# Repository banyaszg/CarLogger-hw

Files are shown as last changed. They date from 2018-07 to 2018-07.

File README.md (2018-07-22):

# CarLogger-hw
OBD-II CAN logger based on Particle Electron(Photon). With Particle Electron it can monitor 2 CAN buses. So it can handle the Medium Speed CAN bus of Mazda and Ford cars.

# Motivation
My main project is designing a remote surveillance system for my car, which connects to the OBD-II CAN buses and sends notification to my phone. I'm mainly interested in security related information (lock, doors, alarm), and battery power. So the standard OBD communication protocol doesn't cover these signals. I have to find them in the proprietary communication. I designed this device to check whether I can reverse engineer the needed part of the Mazda communication protocol.
This device can also be used as the first version of the surveillance system. It has 3 extension connectors for GPS an other sensors.

# Features
* 2 High-speed CAN transceivers
* Power from the OBD-II port using a DC/DC buck converter
* Use with Particle Photon (1 CAN) or Particle Electron (2 CAN)
* MicroSD card
* Battery monitoring
* With Particle Electron and battery it can turn off the DC/DC converter to save the car's battery
* The CAN transceivers can work from the battery of the Particle Electron
* 3 [Grove](http://wiki.seeedstudio.com/Grove_System/) compatible connectors

# Hardware
* [Schematic (PDF)](CarLogger.PDF)
* [Gerber](Gerber)
* [Drill](NC-Drill)
* [Bill of materials](BOM/Bill%20of%20Materials-CarLogger.xls) (Use Grove connectors instead of JST!)
* The PCB fits into this [case](https://www.aliexpress.com/item/16Pin-OBD2-Connector-J1962m-Handle-Connector-DIY/32782473183.html)

A Particle [Photon](https://docs.particle.io/datasheets/photon-(wifi)/photon-datasheet/) or [Electron](https://docs.particle.io/datasheets/electron-(cellular)/electron-datasheet/) is required.

# Software
* The [CarLogger firmware](https://github.com/banyaszg/CarLogger-sw) is used for logging.

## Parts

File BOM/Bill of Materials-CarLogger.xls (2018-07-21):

Comment | Datasheet URL | Description | Designator | Footprint | LibRef | Manufacturer | Manufacturer Part Number | Quantity
100nF |  | Capacitor | C3, C4, C8, C11 | FP_0805_CAP_085 | CAP | TDK | CGA4J3X7T2E104K125AA | 4
100uF |  | Polarized Capacitor | C7 | FP_7343 | CAP_ELECT | KEMET | T495X107K025ATE150 | 1
47uF |  | Capacitor | C9 | FP_1210_CAP_250 | CAP | Murata | GRM32ER61C476KE15L | 1
1uF |  | Capacitor | C10 | FP_0805_CAP_085 | CAP | KEMET | C0805C105J4RACTU | 1
PESD1CAN | https://datasheet.ciiva.com/22692/109497-22692467.pdf | CAN Bus ESD Protection Diode, 200 W, 24 V, -65 to 150 degC, 3-Pin SOT23, RoHS, Tape and Reel | D1, D2 | FP_SOT23-3 | CMP-2000-04916-1 | NXP Semiconductors |  | 2
SCHOTTKY |  | Schottky diode | D3 | FP_SOD-123 | SCHOTTKY | ON Semiconductor / Fairchild | SS34FA | 1
TPSMF4L17A |  | Zener Diode | D4 | FP_SOD-123 | ZENER | Littelfuse | TPSMF4L17A | 1
BAT54SLT1G |  | Dual Series Schottky Barrier Diodes, 3-Pin SOT-23, Pb-Free, Tape and Reel | D5 | FP_SOT23-3 | CMP-1055-00536-1 | On Semiconductor |  | 1
MF-MSMF110/24X-2 | http://www.bourns.com/docs/Product-Datasheets/mfmsmf.pdf | PTC Resettable Fuse, 24 V, 1.1 A, -40 to 85 degC, 2-Pin SMD, RoHS, Tape and Reel | F1 | MF-MSMF-2 | PPTC-2 | Bourns |  | 1
OBDII |  | .1" headers, two rows of 8 each | P1 | OBDII-COMTECH | M08X2-OBDII |  |  | 1
B4B-PH-K-S(LF)(SN) | http://datasheet.octopart.com/B4B-PH-K-S%28LF%29%28SN%29-JST-datasheet-10558886.pdf | Male Header, Pitch 2 mm, 1 x 4 Position, Height 6 mm, Tail Length 3.4 mm, -25 to 85 degC, RoHS, Bulk | P2, P3, P4 | JST-B4B-PH-K-S_V | CMP-2000-05165-1 | JST |  | 3
BSS138 |  | NXP - BSP030,115 - MOSFET, N CH, 30V, 10A, SOT223 | Q1 | FP_SOT23-3 | BSS138 | ON Semiconductor / Fairchild | BSS138 | 1
4.7K |  | Resistor | R2, R3, R7, R8 | FP_0805_RES | RES | Vishay | CRCW08054K70FKEA | 4
348 |  | Resistor | R9 | FP_0805_RES | RES | Vishay | CRCW0805348RFKEA | 1
100K |  | Resistor | R10 | FP_0805_RES | RES | Panasonic | ERJ-6ENF1003V | 1
62K |  | Resistor | R14 | FP_0805_RES | RES | Vishay | CRCW080562K0FKEA | 1
10K |  | Resistor | R15 | FP_0805_RES | RES | Vishay Dale | CRCW080510K0FKTA | 1
503398-1892 | http://www.molex.com/pdm_docs/sd/5033981892_sd.pdf | Micro SD Connector, Pitch 1.1 mm, 8 Position, Height 1.4 mm, -25 to 85 degC, RoHS, Tape and Reel | SD1 | MOLX-SD-503398 | CMP-2000-05621-1 | Molex |  | 1
SN65HVD230QD |  | Automotive Catalog 3.3 V CAN Transceiver, 17 mA, -40 to 125 degC, 8-pin SOIC (D), Green (RoHS & no Sb/Br) | U1, U2 | FP_SOIC8 | CMP-0315-00028-2 | Texas Instruments |  | 2
PTH08080W |  | PTH08080W 2.25-A, WIDE-INPUT ADJUSTABLE SWITCHING REGULATOR | U3 | PTH08080W | TI-PTH08080W | Texas Instruments | PTH08080WAH | 1
Particle Electron footprint |  |  | U4 | ELECTRON | ELECTRON_WITH_HEADERS |  |  | 1

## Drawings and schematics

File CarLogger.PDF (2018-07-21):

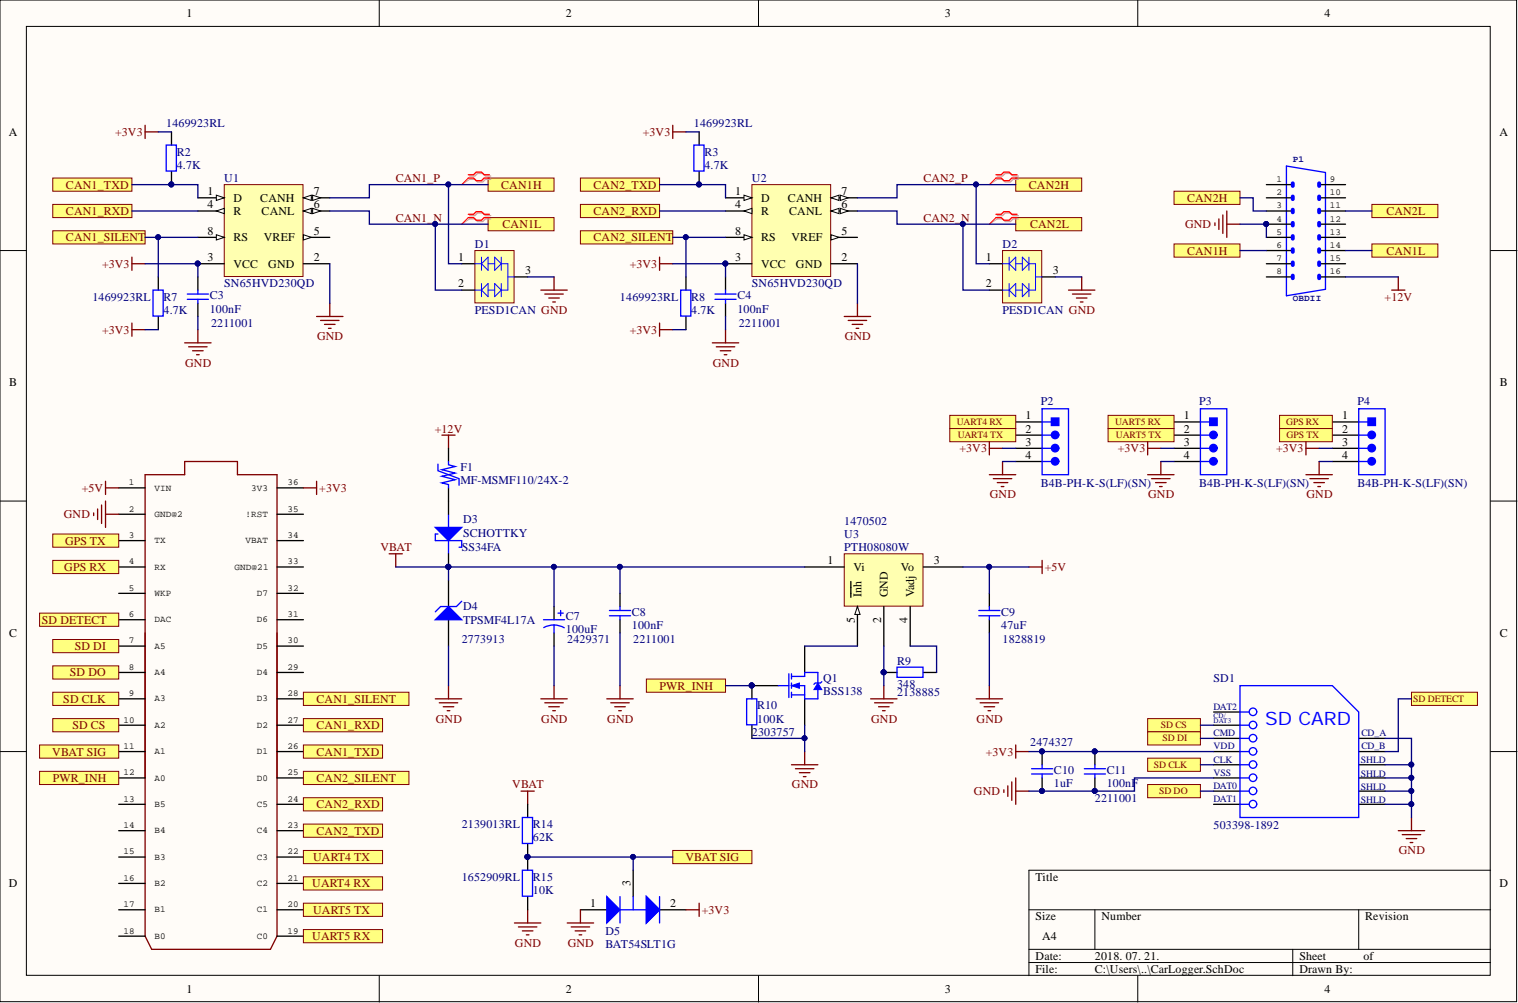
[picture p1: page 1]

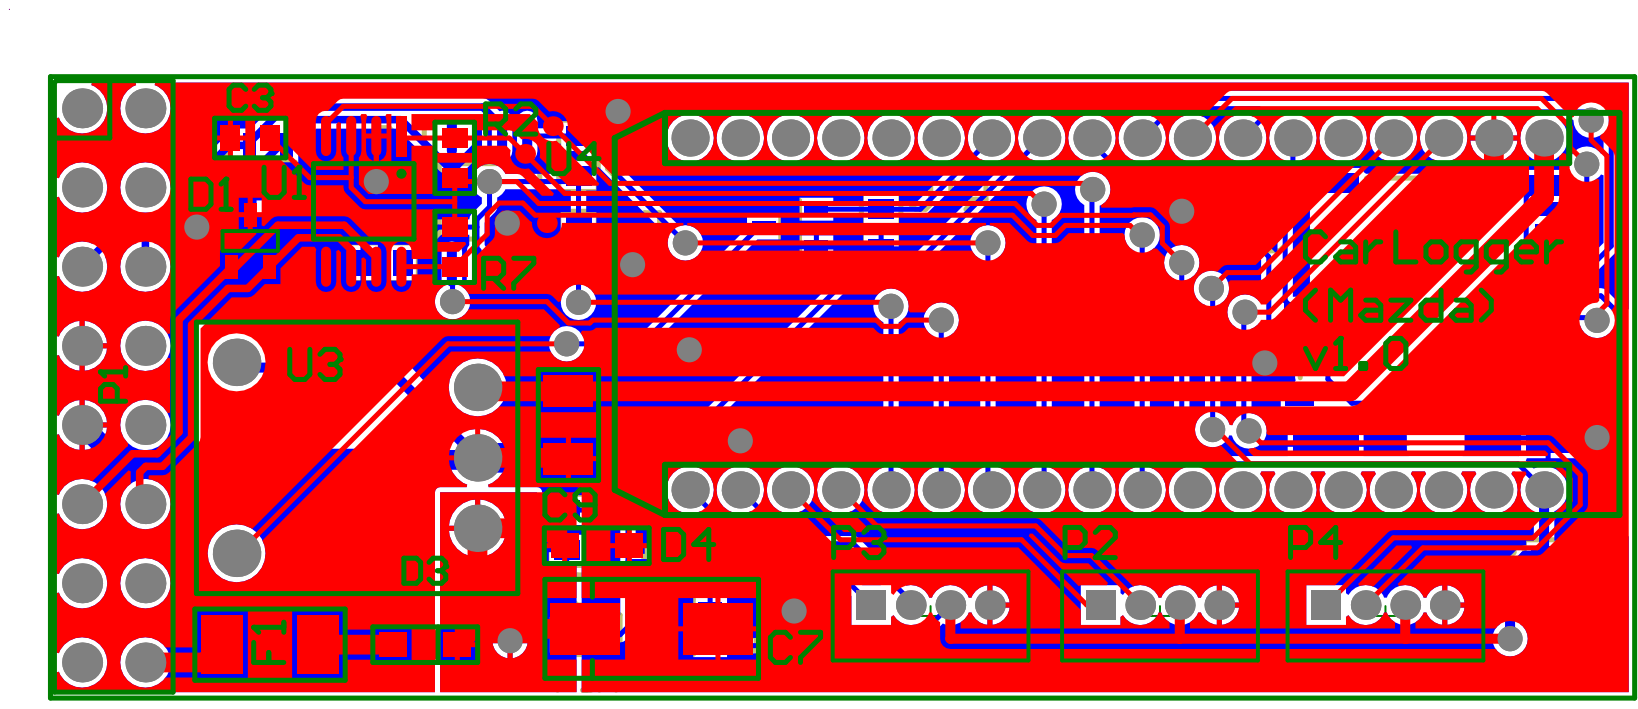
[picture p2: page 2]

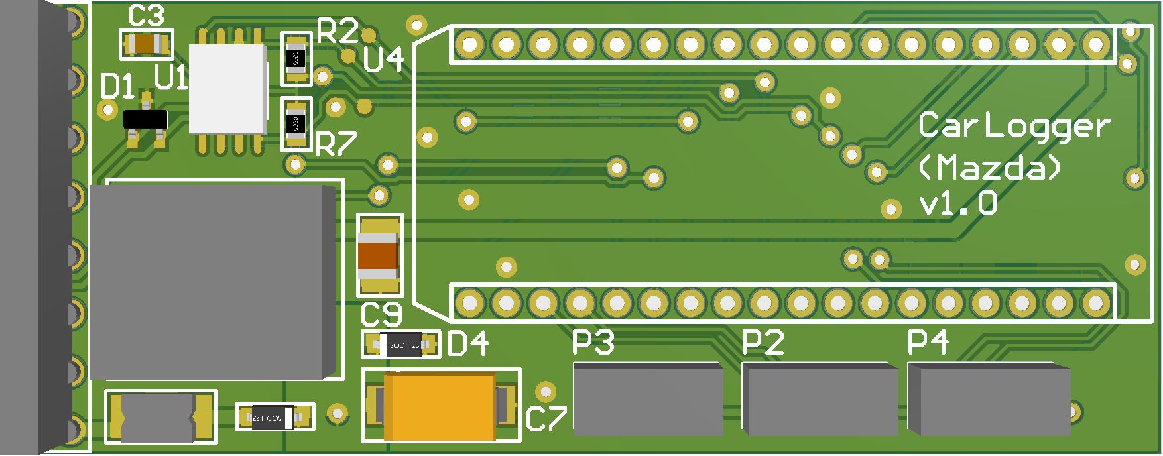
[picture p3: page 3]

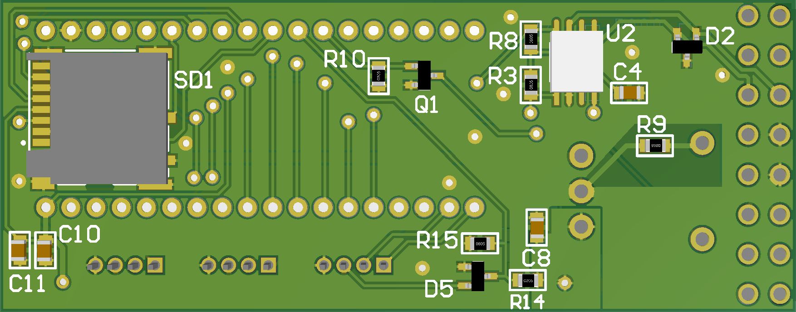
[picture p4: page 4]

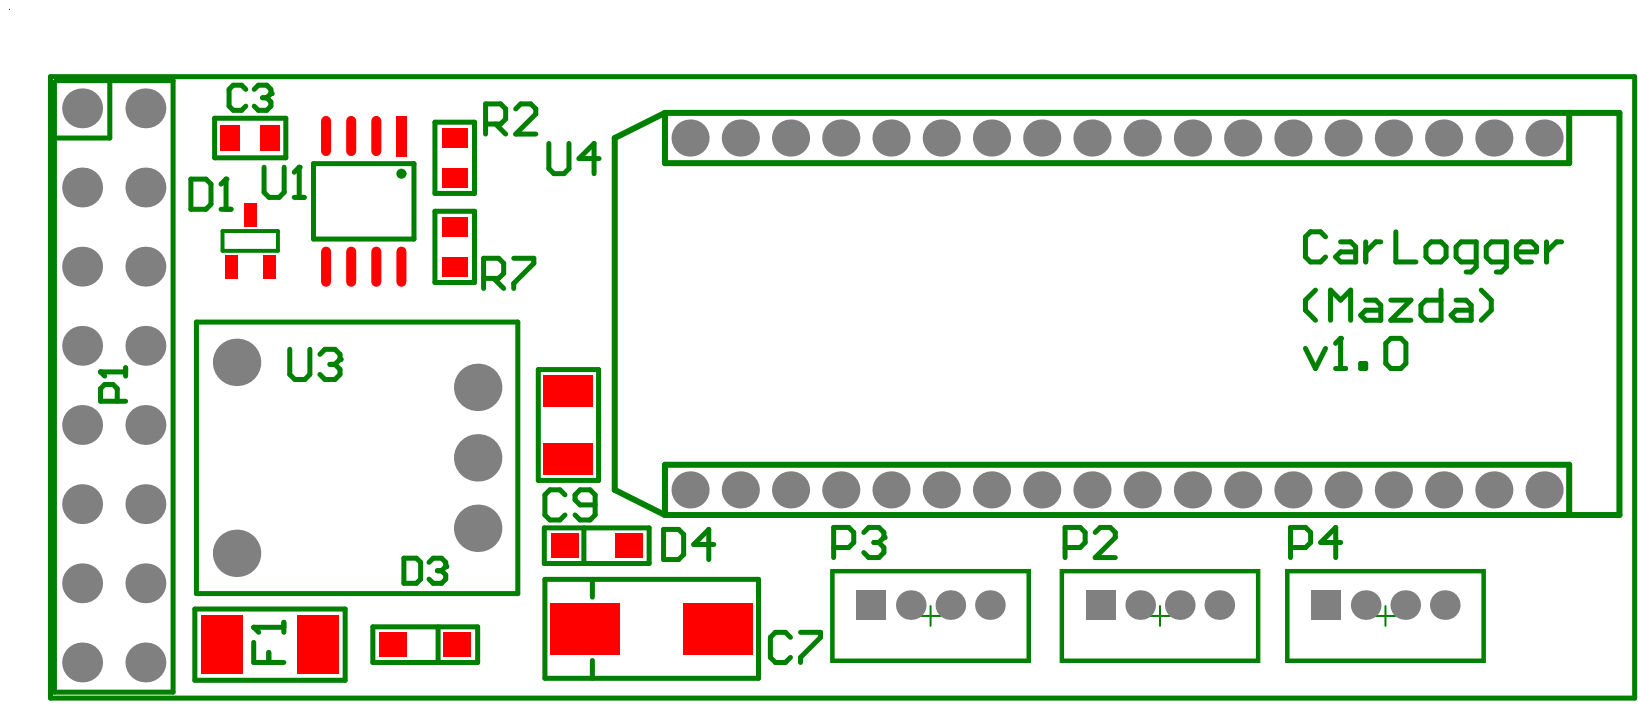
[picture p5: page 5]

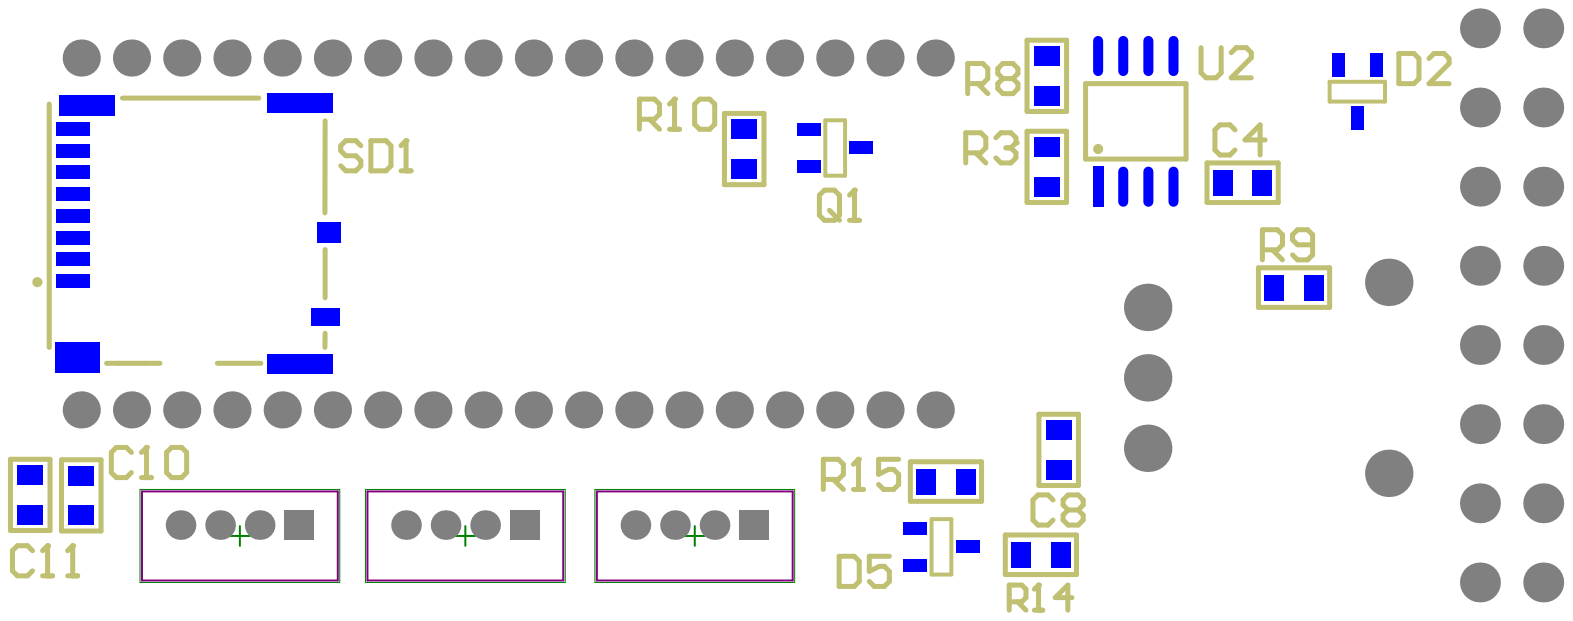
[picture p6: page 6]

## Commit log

2018-07-21 First version
    [Bill of Materials-CarLogger.xls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]
2018-07-22 drill folder fix
